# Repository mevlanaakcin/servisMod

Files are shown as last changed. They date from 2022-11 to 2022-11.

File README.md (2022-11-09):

# servisMod
Okul Servis Araçlarında Öğrenci Koltuk Sensör Sistemi (TSE-EMC Belgeli)
<br>
<br>
<h3>PCB Tasarımı</h3><br>
Elektronik devre şeması ve PCB board tasarımı Eagle de tasarlandı.<br>


<br>
Mikrokontrolör olarak ATMEGA2560-16U Mikrodenetleyici kullanıldı.<br>
TSE'den <strong>EMC Belgesi</strong> alınan bir projedir.<br>
Servis koltuklarında bulunan sensörlerdeki yolcunun oturup oturmadığını algılayıp, yorumlayıp bluetooth ile şoförün android cihazına aktarır. Şoför buradan koltukların durumunu takip edebilir.
Eğer herhangi bir yolcu içeride unutulursa aracın korna ve park lambaları çevreyi uyaracak şekilde çalışacaktır.

<br>
<h5>Üretilmiş, Dizgisi yapılmış ve Yazılımı yüklenip test Edilmiş Hali</h5>


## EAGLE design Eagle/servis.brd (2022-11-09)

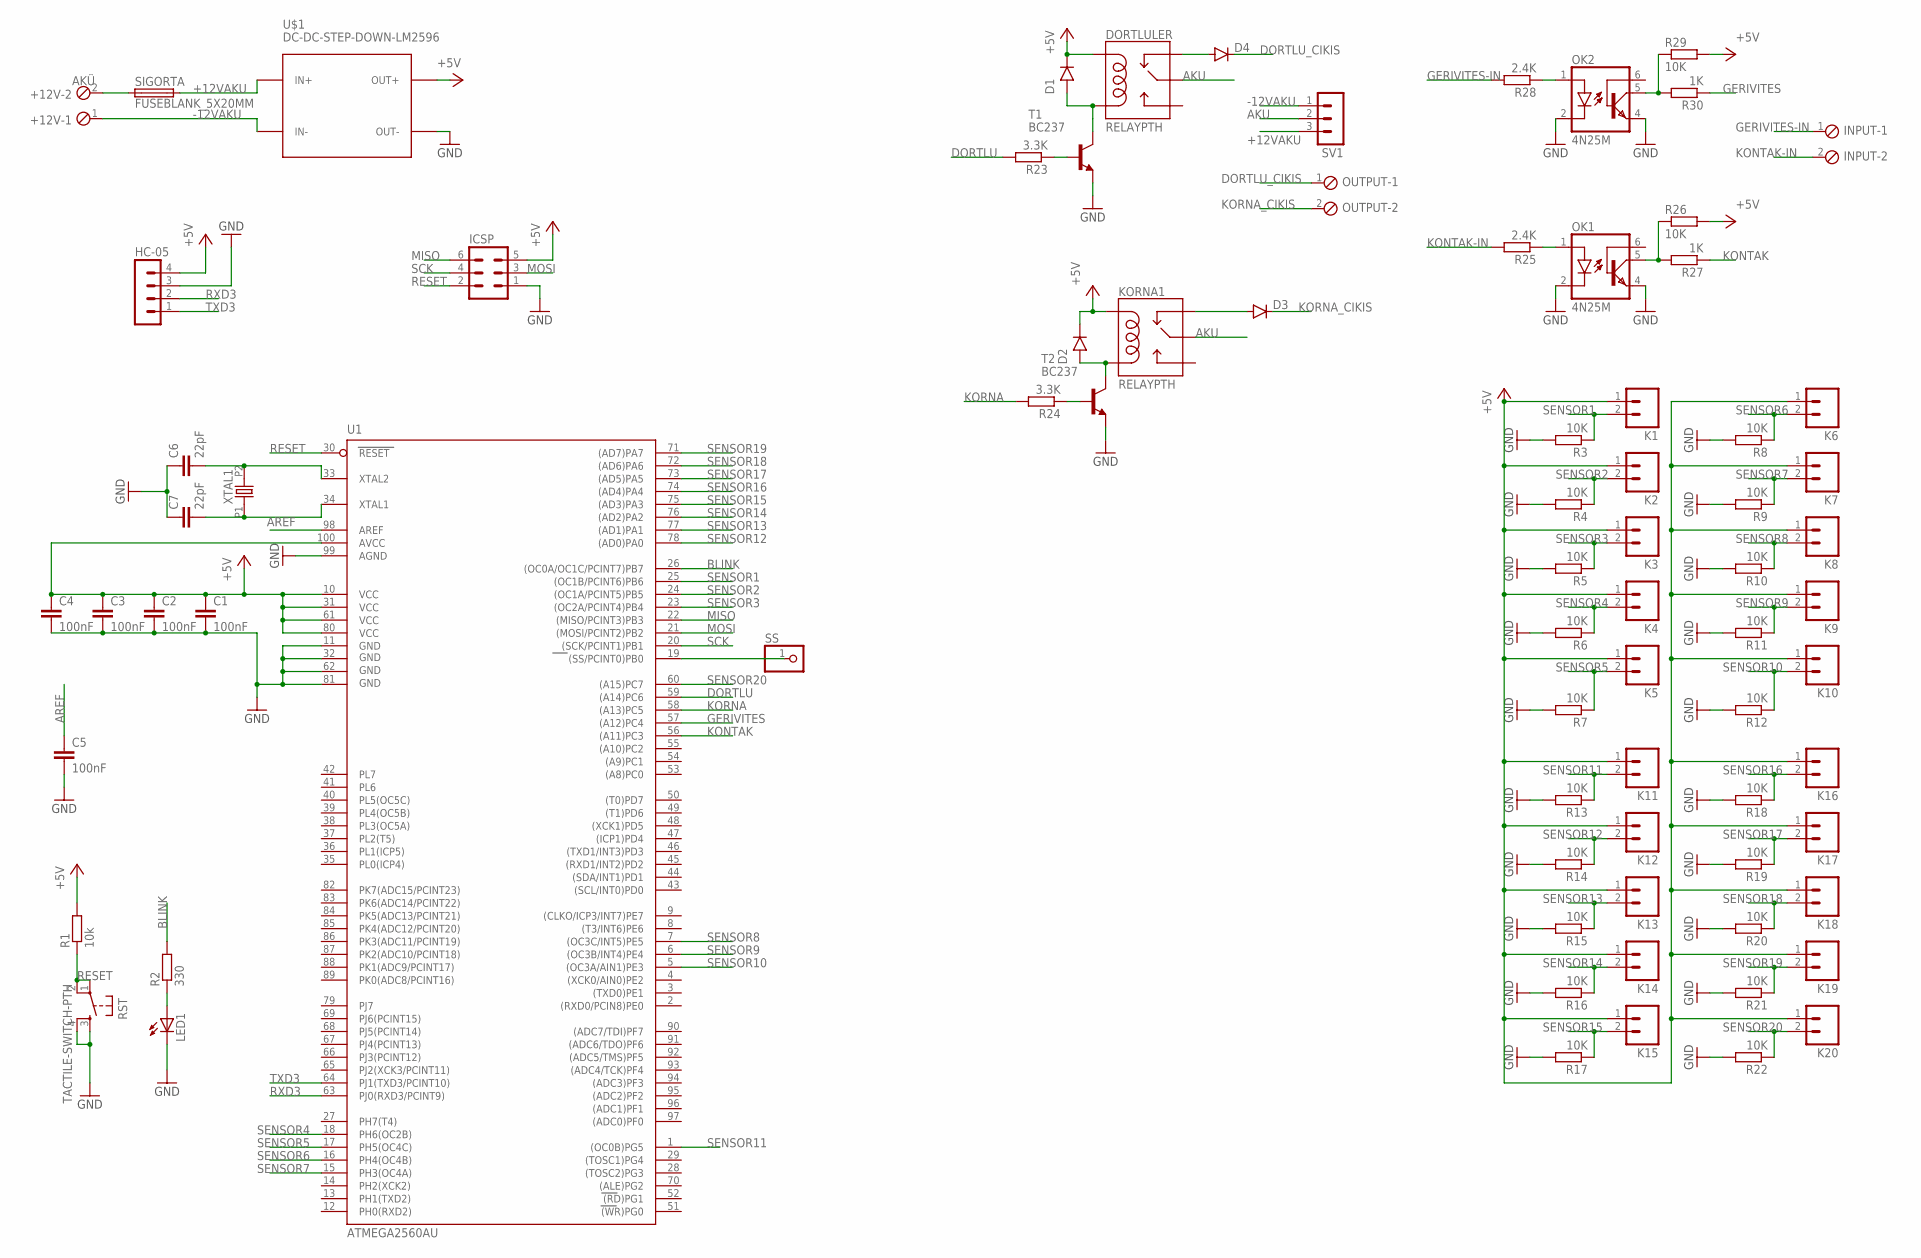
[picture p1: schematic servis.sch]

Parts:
+12V: AKÜ; 2POL254
C1, C2, C3, C4, C5: 100nF; SPARKFUN_0805
C6, C7: 22pF; SPARKFUN_0805
D1, D2: 1N4001; DO41-10
D3, D4: DIODEPTH; DIODE-1N4001
DORTLULER: RELAYPTH; SRD-05VDC-SL-C
HC-05: MA04-1
ICSP: MA03-2
INPUT: AKÜ; 2POL254
K1, K2, K3, K4, K5, K6, K7, K8, K9, K10, K11, K12, K13, K14, K15, K16, K17, K18, K19, K20: SPARKFUN_M02-JST-2-PTH-NO_SILK; SPARKFUN_JST-2-PTH-NS
KORNA1: RELAYPTH; SRD-05VDC-SL-C
LED1: SPARKFUN_LED3MM
OK1, OK2: 4N25M; DIL06
OUTPUT: AKÜ; 2POL254
R1: 10k; R805
R2: 330; R805
R3, R4, R5, R6, R7, R8, R9, R10, R11, R12, R13, R14, R15, R16, R17, R18, R19, R20, R21, R22, R26, R29: 10K; R805
R23, R24: 3.3K; R805
R25, R28: 2.4K; R805
R27, R30: 1K; R805
RST: TACTILE-SWITCH-PTH; TAC-SWITCH-PTH
SIGORTA: FUSEBLANK_5X20MM; FUSE_HOLDER_5X20MM
SS: PINHD-1X1; 1X01
SV1: MA03-1
T1, T2: BC237; TO92
U1: ATMEGA2560AU; TQFP100
U$1: DC-DC-STEP-DOWN-LM2596
XTAL1: OSC-XTAL-HC-49U-PTH; HC-49U-PTH

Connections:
+5V: C1.1, C2.1, C3.1, C4.1, D1.C (CATHODE), D2.C (CATHODE), DORTLULER.COIL1, HC-05.4, ICSP.5, K1.1, K2.1, K3.1, K4.1, K5.1, K6.1, K7.1, K8.1, K9.1, K10.1, K11.1, K12.1, K13.1, K14.1, K15.1, K16.1, K17.1, K18.1, K19.1, K20.1, KORNA1.COIL1, R1.2, R26.2, R29.2, U1.10 (VCC), U1.31 (VCC1), U1.61 (VCC2), U1.80 (VCC3), U1.100 (AVCC), U$1.OUT+
+12VAKU: SIGORTA.2, SV1.3, U$1.IN+
-12VAKU: +12V.1, SV1.1, U$1.IN-
AKU: DORTLULER.SWCOMMON, KORNA1.SWCOMMON, SV1.2
AREF: C5.1, U1.98 (AREF)
BLINK: R2.2, U1.26 ((OC0A/OC1C/PCINT7)PB7)
DORTLU: R23.2, U1.59 ((A14)PC6)
DORTLU_CIKIS: D4.C, OUTPUT.1
GERIVITES: R30.1, U1.57 ((A12)PC4)
GERIVITES-IN: INPUT.1, R28.2
GND: C1.2, C2.2, C3.2, C4.2, C5.2, C6.1, C7.1, HC-05.3, ICSP.1, LED1.K (C), OK1.2 (C), OK1.4 (EMI), OK2.2 (C), OK2.4 (EMI), R3.2, R4.2, R5.2, R6.2, R7.2, R8.2, R9.2, R10.2, R11.2, R12.2, R13.2, R14.2, R15.2, R16.2, R17.2, R18.2, R19.2, R20.2, R21.2, R22.2, RST.3, RST.4, T1.1 (E), T2.1 (E), U1.11 (GND), U1.32 (GND1), U1.62 (GND2), U1.81 (GND3), U1.99 (AGND), U$1.OUT-
KONTAK: R27.1, U1.56 ((A11)PC3)
KONTAK-IN: INPUT.2, R25.2
KORNA: R24.2, U1.58 ((A13)PC5)
KORNA_CIKIS: D3.C, OUTPUT.2
KRISTAL: C6.2, U1.33 (XTAL2), XTAL1.P2 (2)
KRISTAL_2: C7.2, U1.34 (XTAL1), XTAL1.P1 (1)
MISO: ICSP.6, U1.22 ((MISO/PCINT3)PB3)
MOSI: ICSP.3, U1.21 ((MOSI/PCINT2)PB2)
unnamed: R23.1, T1.2 (B)
unnamed: D3.A, KORNA1.SWCLOSED (SWCLOSE)
unnamed: D4.A, DORTLULER.SWCLOSED (SWCLOSE)
unnamed: LED1.A, R2.1
unnamed: SS.1, U1.19 ((SS/PCINT0)PB0)
unnamed: R24.1, T2.2 (B)
unnamed: D1.A (ANODE), DORTLULER.COIL0, T1.3 (C)
unnamed: D2.A (ANODE), KORNA1.COIL0, T2.3 (C)
unnamed: OK1.1 (A), R25.1
unnamed: OK1.5 (COL), R26.1, R27.2
unnamed: +12V.2, SIGORTA.1
unnamed: OK2.1 (A), R28.1
unnamed: OK2.5 (COL), R29.1, R30.2
RESET: ICSP.2, R1.1, RST.1, RST.2, U1.30 (RESET)
RXD3: HC-05.2, U1.63 (PJ0(RXD3/PCINT9))
SCK: ICSP.4, U1.20 ((SCK/PCINT1)PB1)
SENSOR1: K1.2, R3.1, U1.25 ((OC1B/PCINT6)PB6)
SENSOR2: K2.2, R4.1, U1.24 ((OC1A/PCINT5)PB5)
SENSOR3: K3.2, R5.1, U1.23 ((OC2A/PCINT4)PB4)
SENSOR4: K4.2, R6.1, U1.18 (PH6(OC2B))
SENSOR5: K5.2, R7.1, U1.17 (PH5(OC4C))
SENSOR6: K6.2, R8.1, U1.16 (PH4(OC4B))
SENSOR7: K7.2, R9.1, U1.15 (PH3(OC4A))
SENSOR8: K8.2, R10.1, U1.7 ((OC3C/INT5)PE5)
SENSOR9: K9.2, R11.1, U1.6 ((OC3B/INT4)PE4)
SENSOR10: K10.2, R12.1, U1.5 ((OC3A/AIN1)PE3)
SENSOR11: K11.2, R13.1, U1.1 ((OC0B)PG5)
SENSOR12: K12.2, R14.1, U1.78 ((AD0)PA0)
SENSOR13: K13.2, R15.1, U1.77 ((AD1)PA1)
SENSOR14: K14.2, R16.1, U1.76 ((AD2)PA2)
SENSOR15: K15.2, R17.1, U1.75 ((AD3)PA3)
SENSOR16: K16.2, R18.1, U1.74 ((AD4)PA4)
SENSOR17: K17.2, R19.1, U1.73 ((AD5)PA5)
SENSOR18: K18.2, R20.1, U1.72 ((AD6)PA6)
SENSOR19: K19.2, R21.1, U1.71 ((AD7)PA7)
SENSOR20: K20.2, R22.1, U1.60 ((A15)PC7)
TXD3: HC-05.1, U1.64 (PJ1(TXD3/PCINT10))

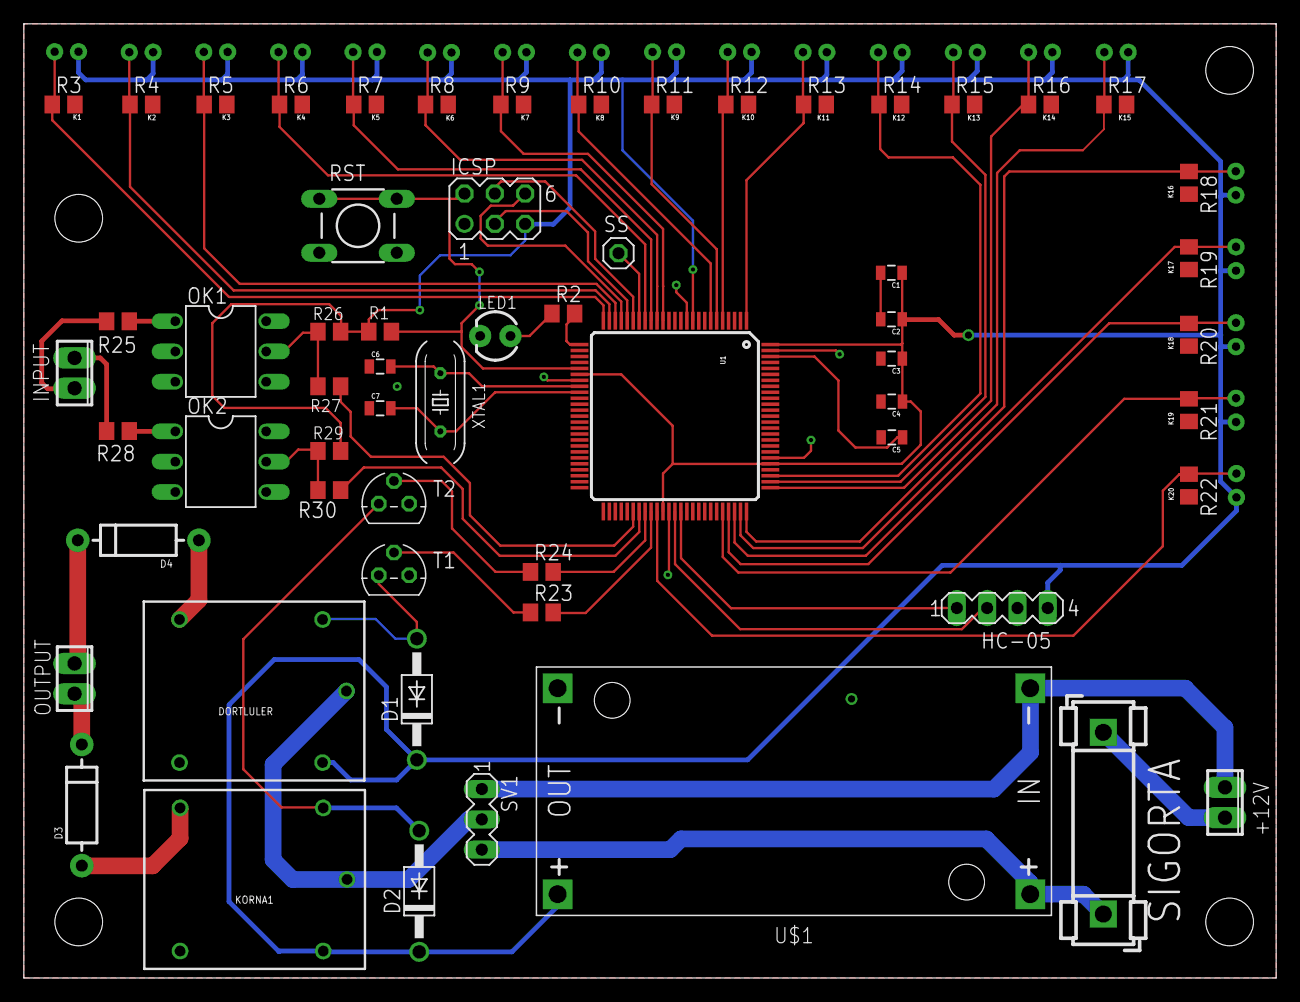
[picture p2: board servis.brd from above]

Board: 2 copper layers, 105.0 x 80.0 mm, 80 parts (0 on the bottom side), 56 nets.

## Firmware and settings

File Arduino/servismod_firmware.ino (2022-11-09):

#include<SoftwareSerial.h>
SoftwareSerial BTSerial(15,14); // RX,TX
//#define kornaRole 32
//#define dortluRole 31
#define kontakBilgi 34
#define gerivitesBilgi 33

int sensorPin[20]={12,11,10,9,8,7,6,3,2,5,4,22,23,24,25,26,27,28,29,30};
String koltukDurum[20]={};
String yolcuDurum;
boolean hata=0;



void sensorOkuma(){
for(int i=0;i<20;i++){
 String koltukDurumEski=koltukDurum[i];
 koltukDurum[i]=digitalRead(sensorPin[i]); 
 delay(100);
 if(koltukDurumEski!=koltukDurum[i])
 {
 String veri=String(i)+"f"+String(koltukDurum[i]);
 BTSerial.println(veri);
}
else{}

}
}
String koltukKontrol(){
  for(int i=0;i<20;i++){
    if(koltukDurum[i]=="1"){
    yolcuDurum="1";
    break;
    }
    else{
      yolcuDurum="0";
      }
  }
  return yolcuDurum;
}


void setup() {
  BTSerial.begin(9600);
  for(int i=0;i<20;i++){
  pinMode(sensorPin[i],INPUT);
  }
  pinMode(13, OUTPUT);
 // pinMode(kornaRole,OUTPUT);
 // pinMode(dortluRole,OUTPUT);
  pinMode(kontakBilgi,INPUT);
  pinMode(gerivitesBilgi,INPUT);
  //Rölelerin elektronik devresi ters mantık bağlantılı olduğundan çıkışları HIGH yaptık
 // digitalWrite(kornaRole,HIGH);
 // digitalWrite(dortluRole,HIGH);
}
/*
kontakBilgi ve gerivitesBilgi enerji varken LOW değer döndürüyor.
DİKKAT: Araçların incelenmesi gerekiyor. Kontakta anahtar varken veya yokken hangi bilgiler geliyor.
*/
void loop() {

while(digitalRead(kontakBilgi)==1 && koltukKontrol()=="1"){
    
   if(hata==0){
  BTSerial.println("404");
  delay(400);
  BTSerial.println("404");
   hata=1;
   }
 /* 
  digitalWrite(dortluRole,LOW);
  delay(1000);
  digitalWrite(kornaRole,LOW);
  delay(2000);
  digitalWrite(kornaRole,HIGH);
  */

  if(digitalRead(kontakBilgi)==0){
  //  digitalWrite(dortluRole,HIGH);
   // digitalWrite(kornaRole,HIGH);
      yolcuDurum="0";
    BTSerial.println("200");
    hata=0;
    break;
  }
  
}

sensorOkuma(); 
//digitalWrite(dortluRole,HIGH);
//digitalWrite(kornaRole,HIGH);


}

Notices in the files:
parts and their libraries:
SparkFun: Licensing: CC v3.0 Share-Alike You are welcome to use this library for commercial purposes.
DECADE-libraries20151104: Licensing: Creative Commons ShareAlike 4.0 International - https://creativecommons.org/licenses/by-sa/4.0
